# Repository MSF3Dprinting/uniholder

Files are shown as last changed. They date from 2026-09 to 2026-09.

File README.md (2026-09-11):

# UniHolder v1.0

Parametric OpenSCAD holder for items of any size, mountable on walls, vertical or horizontal poles and TS35 DIN rails. Every part prints exactly as generated, standing, with no supports and no overhang beyond `max_overhang`; nothing protrudes into the item space. Made for MSF 3D Printing for All. Design plan: `docs/uniholder_design_plan.md` · test report: `docs/test_report.md`.

## Files

| Path | Content |
|---|---|
| `uniholder.scad` | Main file with all Customizer parameters (needs the `lib/` folder next to it) |
| `uniholder_customizer.scad` | The same model as one self-contained file, for online Customizers running OpenSCAD 2021.01 or newer; tested to give identical geometry |
| `lib/` | `uh_core` maths and screw table · `uh_shapes` printable primitives · `uh_body` shell, walls, hexagons, front opening · `uh_din` DIN rail clip · `uh_mount` back holes, wings, pole mounts |
| `tests/` | `test_shapes.scad` calibration sheet · `test_checker_fail.scad` deliberately unprintable part · variant lists `st2`–`st5` · `examples.json` |
| `tools/` | `run_all_tests.py` complete test suite · `check_overhang.py` STL printability check · `render_matrix.py` batch render · `build_single_file.py` rebuilds the Customizer file |
| `docs/` | Design plan, test report, preview images |

## Quick start

Open `uniholder.scad` or `uniholder_customizer.scad`, show the Customizer (Window → Customizer), set the parameters, render with F6 and export the STL. The console lists `UH INFO` lines (finished size, screws to use) and `UH WARNING` lines when a setting had to be adjusted to fit.

| Tab | Sets |
|---|---|
| Print | `part`: holder · din_clip · holder_and_clip (both on one bed) · din_preview (clip shown mounted, viewing only); overhang limit; quality |
| Size | Item size (inner) or holder size (outer), clearance |
| Walls and edges | Wall, back and floor thickness, corner radii, chamfers, floor cove |
| Wall styles · Hex pattern | Each wall and the floor solid or hexagon-perforated; hexagon size, strut, margins |
| Front opening | Open front with retaining lip and side edges, or a vertical slot |
| Back holes | Ø3–10 mm, plain / countersink / counterbore / keyhole, columns × rows, spacing |
| Wings | Left / right / both, length, thickness, height, on the bed or raised, holes, gusset |
| Pole mount | Vertical or horizontal pole, diameter, V angle, zip ties (count, size, clearance) |
| DIN rail clip | Clip bolt holes in the back wall, bolt size M3–M6, rail height, clip width |

## Printing

- Print exactly as generated and do not rotate the part: the orientation is part of the design. No supports.
- PETG (a light colour for clinical areas), 0.2 mm layers, 4 perimeters, 20–40 % infill (upper end for wings, pole blocks and the clip).
- `max_overhang` = 60 by default; use 45 on printers with weak part cooling — all geometry adapts.
- DIN clip: prints standing on its profile. Enable elephant-foot compensation (about 0.2 mm) so the spring gaps stay open at the first layer.

## Mounting

- **Back holes and wings:** screws matching the hole diameter (default 4.5 mm: M4 or 4 mm wood screws). Countersunk, counterbored and keyhole heads sit flush inside the back wall, which thickens automatically; plain holes leave the head on the inner face.
- **Poles:** standard 5 × 2 mm zip ties (tunnels are 5.5 × 2.5 mm with the default 0.5 mm clearance).
- **DIN rail:** the clip is a separate part. Set `din_holes = true` and choose `din_bolt` (M3–M6); export the holder with `part = holder` and the clip with `part = din_clip`, or both with `part = holder_and_clip`. `part = din_preview` shows the clip mounted on a rail for checking only. The console names the screws, e.g. *2 × M4 × 10 countersunk screws and 2 × M4 nuts*. Put the nuts into the clip's pockets and screw the holder to the clip from inside. Hook the clip over the top of the rail and press the bottom until the latch snaps. To remove, lever the release tab below the spring down with a flat screwdriver and tilt the holder off.

| din_bolt | Hole | Nut | Clip width (auto) | Clip plate | Countersunk screw with default walls |
|---|---|---|---|---|---|
| M3 | 3.4 mm | 5.5 mm AF | 36 mm | 5.0 mm | M3 × 8 |
| M4 | 4.5 mm | 7 mm AF | 36 mm | 5.0 mm | M4 × 10 |
| M5 | 5.5 mm | 8 mm AF | 36 mm | 6.3 mm | M5 × 12 |
| M6 | 6.6 mm | 10 mm AF | 39 mm | 6.8 mm | M6 × 12 |

## Examples

| Example | Parameters (everything else default) |
|---|---|
| Wall cup | defaults: inner 60 × 40 × 80 mm, open front with 20 mm lip, hexagon sides, 2 countersunk back holes |
| Hand-rub bottle on an IV pole | `size_x = 75`, `size_y = 75`, `size_z = 110`, `front_lip_h = 30`, `pole_mount = "vertical"`, `pole_d = 25` |
| DIN rail parts bin | `size_x = 80`, `size_y = 50`, `size_z = 70`, `front_lip_h = 20`, `din_holes = true`; then `part = "din_clip"` |

## Testing

```
python3 tools/run_all_tests.py            # all stages, about 7 minutes; writes docs/test_report.md
python3 tools/run_all_tests.py multi      # one stage: primitives | multi | single | compare | probes | report
```

The suite renders every variant from both `uniholder.scad` and the Customizer file at 60° and 45°, checks each STL for printability, compares the two versions STL by STL, confirms that nothing enters the item space, and fits the DIN clip on a TS35 rail model for every bolt size. Latest result (OpenSCAD 2021.01): primitives pass, 72 of 72 variants pass in each version, 72 of 72 STLs identical, 21 of 21 probes pass — details in `docs/test_report.md`.

For a single model: `python3 tools/check_overhang.py part.stl --max-overhang 60`. After editing `lib/`, rebuild the Customizer file with `python3 tools/build_single_file.py` and rerun the tests.

## Limits

- The DIN clip spring is sized for PETG and standard 1.0 mm TS35 rails (lips up to 1.5 mm); test the snap and release on your own rails before series printing.
- Hexagon hole edges are sharp; cut-out edges are chamfered rather than filleted.
- Features deferred to a later version are listed in the design plan backlog (§8).

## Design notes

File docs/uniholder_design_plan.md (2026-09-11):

# UniHolder — Parametric Universal Holder for OpenSCAD

**Design plan v2.1 (lean) · September 2026** · status: all sub-tasks complete (UniHolder v1.0) — v2.1 adds rule M1 (flush screw heads) after the ST-3 review

v2.0 cuts the v1.1 scope to the core requirements and sizes every remaining sub-task to fit one working session. Nothing is lost: cut features are listed in the backlog (§8).

## 1. Goal

One OpenSCAD file that generates open-top holders for arbitrary items, mountable on walls, vertical or horizontal poles, and DIN rails. Parts print standing, exactly as generated, without supports, and no downward-facing surface exceeds `max_overhang` (60° from vertical by default).

## 2. Scope

| Area | Included |
|---|---|
| Body | Inner or outer size; filleted vertical edges (front and back radius); chamfered top and bed edges; floor cove |
| Walls | Back, left, right, front and floor each solid or hexagon-perforated |
| Front | Solid, hex, **open** (cut down to a retaining lip, side edges kept) or **slot** |
| Wall mounting | Back holes Ø3–10 mm: plain, countersink, counterbore or keyhole, in columns × rows; heads seat flush and the back wall thickens automatically. Wings none / left / right / both: length, height, thickness, holes Ø3–10 mm (count; plain, countersink or slot), gusset |
| Pole mounting | Vertical pole: V-cradle with horizontal zip-tie tunnels. Horizontal pole: V-cradle with vertical zip-tie tunnels |
| DIN rail | Separate TS35 clip with a spring latch, printed on its side, bolted with 2 × M3–M6 bolts through the holder's DIN hole pattern |
| Delivery | Single-file Customizer version; README with print settings and three example configurations |

## 3. Printability rules (unchanged from v1.1)

β = 90° − max_overhang (roof angle above horizontal).

| Rule | Statement |
|---|---|
| P1 | Print as used: Z up, floor on the bed |
| P2 | Downward-facing surfaces ≤ max_overhang from vertical |
| P3 | No floating lowest points: nothing on the holder points downward (hooks and DIN jaws are separate parts) |
| P4 | Horizontal holes are teardrops |
| P5 | Horizontal channels have peaked roofs |
| P6 | Overhanging features get support slopes rising at β |
| P7 | Pointy-top hexagons, whole cells only |
| P8 | Walls and struts ≥ 1.2 mm |
| P9 | Bed edges chamfered 45°, steeper when max_overhang < 45° |
| E1 | Vertical edges filleted |
| E2 | Top edges chamfered |
| E3 | Raised bottom edges sloped at β |
| E4 | Round a corner only where the outline turns upward from a slope |
| M1 | Nothing enters the item space: screw heads seat flush inside the back wall, which thickens as needed (inner mode keeps the item size) |
| — | No text or embossing (cleanability) |

## 4. Conventions

y = 0 is the mounting plane (outer back face); the body extends to −Y and mounts sit at +Y. x = 0 is the centreline; z = 0 is the bed. `0` means auto. `uniholder.scad` holds the parameters and the assembly and includes `lib/uh_core.scad` → `uh_shapes.scad` → `uh_body.scad` → `uh_mount.scad` → `uh_din.scad`. Mount features publish keepout rectangles, so hexagons never cut into mounting zones.

## 5. Customizer parameters (added with their sub-task)

| Tab | Parameters (default) | ST |
|---|---|---|
| Print | max_overhang (60), quality (normal) | 2 |
| Size | size_mode (inner), size_x / size_y / size_z (60 / 40 / 80), item_clr (1) | 2 |
| Walls and edges | wall_t (2.4), back_t (3.2), floor_t (2), corner_r (6), back_corner_r (1.5), chamfer_top (1), chamfer_bottom (0.6), floor_cove (2) | 2 |
| Wall styles | back / left / right / floor_style (solid / hex / hex / solid), front_style (open) | 2 |
| Hex pattern | hex_size (8), hex_strut (2), hex_margin (3), hex_top_band (6), hex_bottom_band (4) | 2 |
| Front opening | front_lip_h (20), front_side_lip_w (8), front_open_r (5), front_slot_w (12), front_slot_z (15) | 2 |
| Back holes | back_holes (true), back_hole_d (4.5), back_hole_style (countersink), back_hole_head_d (0 = 2·d), back_hole_cols (1), back_hole_rows (2), back_hole_pitch_x / z (0 = auto) | 3 |
| Wings | wings (none), wing_len (20), wing_t (4), wing_h (0 = body), wing_align (bottom / top), wing_hole_d (4.5), wing_hole_style (countersink), wing_hole_count (2), wing_gusset (true) | 3 |
| Pole mount | pole_mount (none / vertical / horizontal), pole_d (25), pole_v_angle (90), tie_count (2), tie_w (5), tie_t (2) | 4 |
| DIN clip | part (holder / din_clip / holder_and_clip / din_preview), din_holes (false), din_bolt (M4; M3–M6), din_rail_z (0 = auto), din_clip_w (0 = auto) | 5 |

## 6. Sub-tasks

| ST | Deliverables | Done when |
|---|---|---|
| ST-0 ✓ | Design plan | — |
| ST-1 ✓ | `uh_core.scad`, `uh_shapes.scad`, test sheet, `check_overhang.py` | 8 coupons pass at 60°, 45° and 40° |
| ST-2 ✓ | `uniholder.scad` v0.2, `uh_body.scad`, `render_matrix.py` | Body variants (front modes, hex walls and floor, edge cases) render and pass at 60° and 45° |
| ST-3 ✓ | `uh_mount.scad`: back holes, wings, keepouts | Hole styles and wing variants pass at 60° and 45° |
| ST-4 ✓ | `uh_mount.scad`: vertical and horizontal pole saddles | Pole Ø12–60 mm and tie variants pass at 60° and 45° |
| ST-5 ✓ | `uh_din.scad`, `uniholder_customizer.scad`, README | Clip passes in its print orientation; single file renders the same as the multi-file version |

## 7. Working method per sub-task

1. Write the files.
2. Render a small variant matrix at 60° and 45° in one run (`tools/render_matrix.py`), checking every STL.
3. At most three fix rounds; anything larger moves to the next sub-task.
4. One preview image, then a cumulative zip.

## 8. Backlog (v2)

Slide-in removable front panel, arch window, top hanging tabs, strap slots, magnet pockets, tape recess, dividers, retention lip, clinical-mode switch, slide rail, UMS V1 counterpart (needs reference STEP/STL), HomeRacker pins, French cleat, pegboard / SKÅDIS, edge hook, bolted pole clamp, Customizer JSON presets.

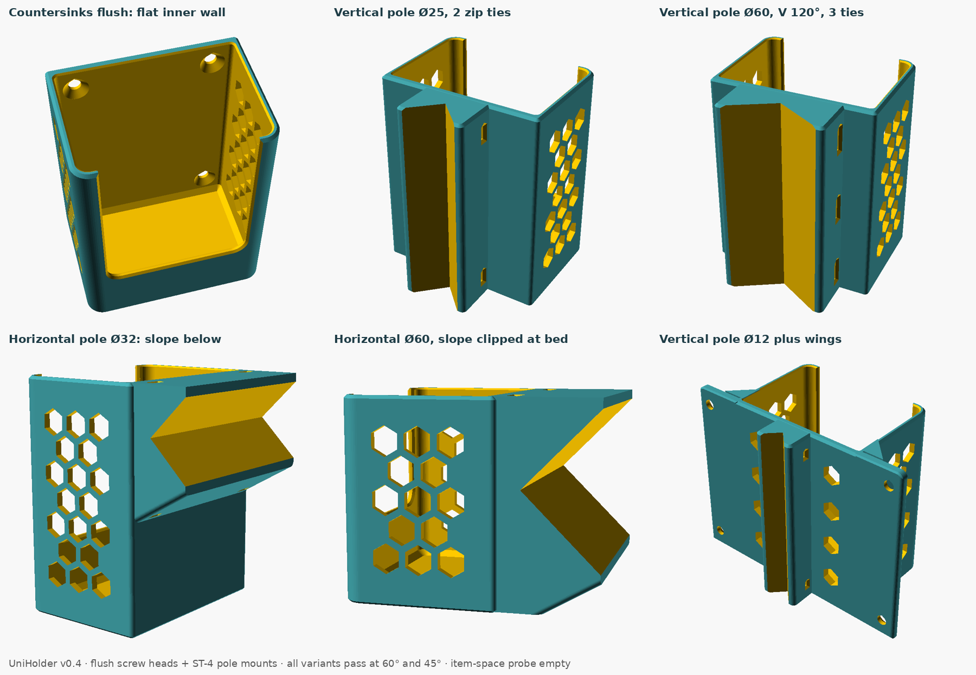
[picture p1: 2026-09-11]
docs/st4_pole_preview.png

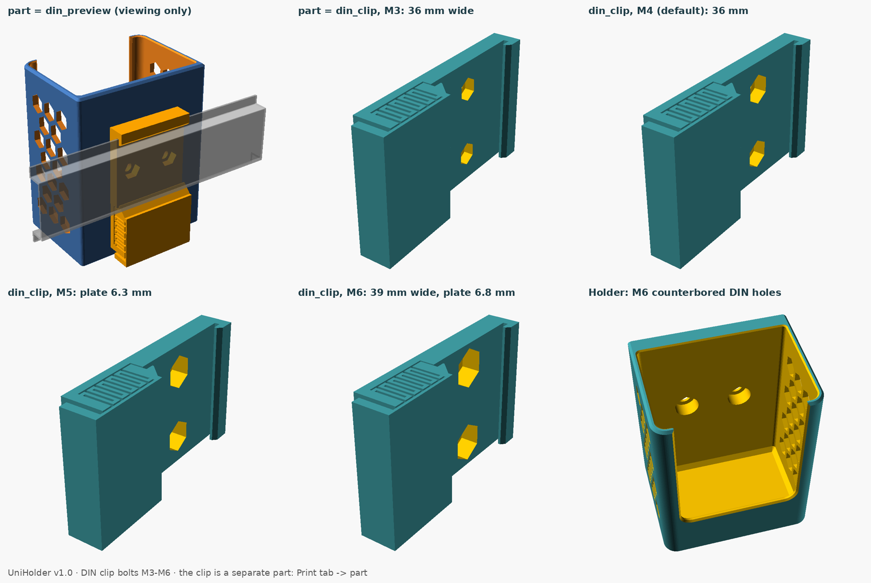
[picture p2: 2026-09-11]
docs/din_bolts_preview.png

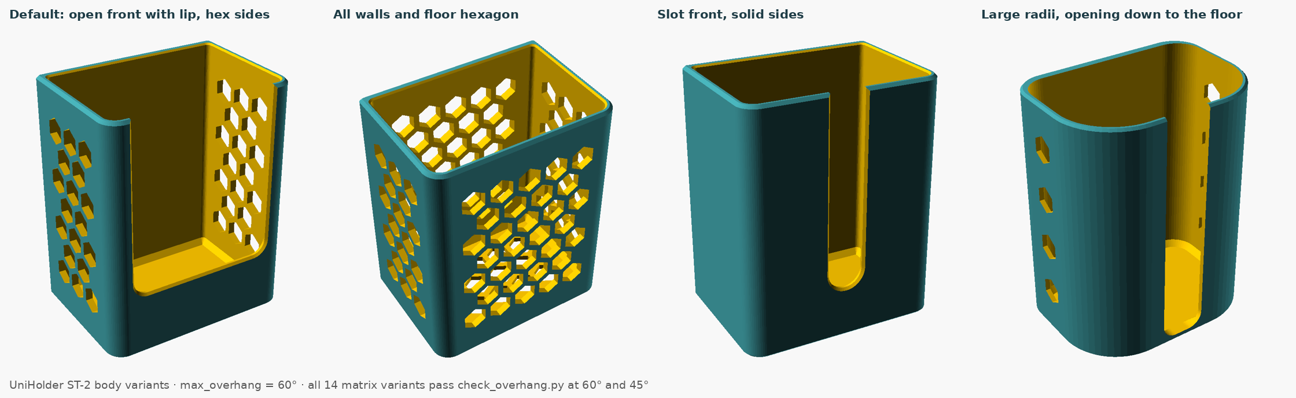
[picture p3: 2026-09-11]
docs/st2_body_preview.png

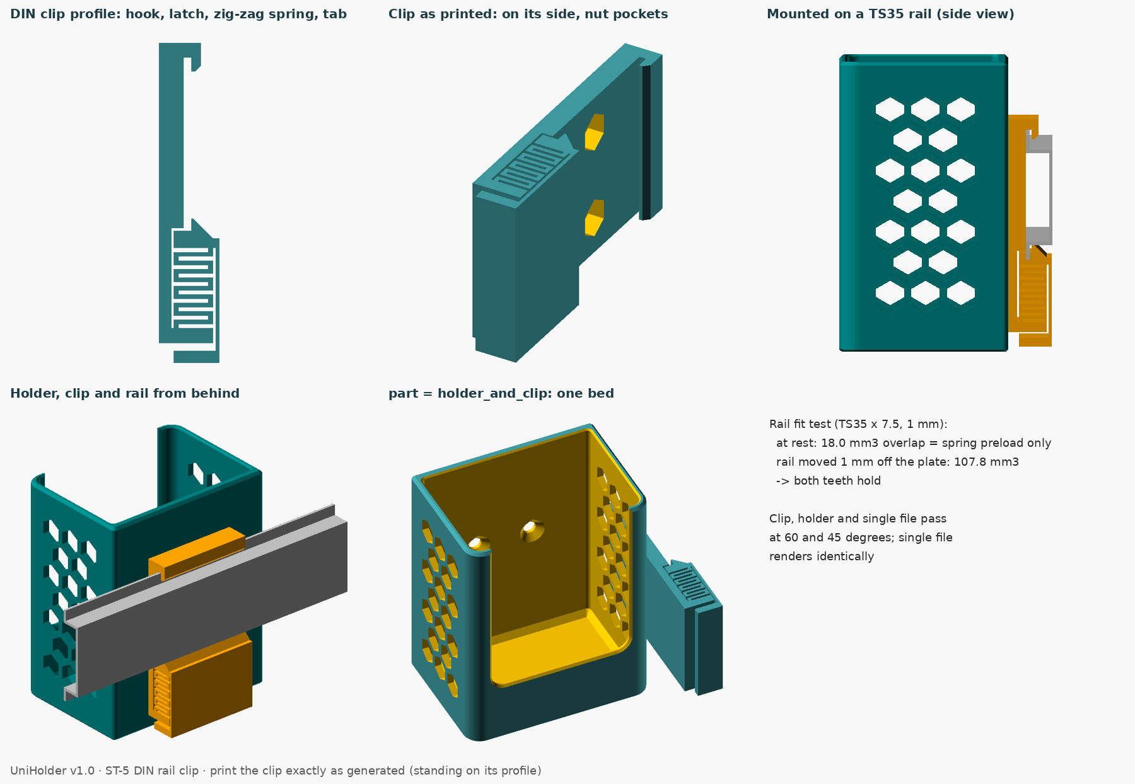
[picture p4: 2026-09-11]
docs/st5_din_preview.png

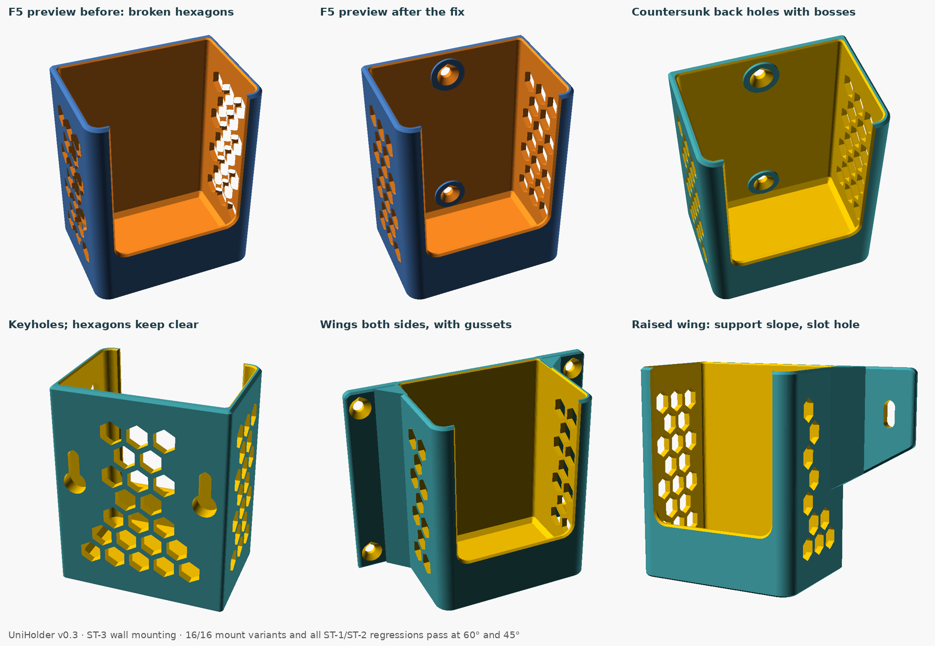
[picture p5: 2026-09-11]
docs/st3_mounting_preview.png

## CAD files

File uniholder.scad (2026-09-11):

// =====================================================================
//  UniHolder — parametric universal holder                        v1.0
//  MSF 3D Printing for All · OpenSCAD 2021.01 or newer · no libraries
//
//  Print exactly as generated: standing on its floor, without supports.
//  No downward-facing surface exceeds max_overhang.
//
//  v1.0 (ST-5): DIN rail clip, single-file Customizer version, zip-tie clearance.
//  v0.4 (ST-4): vertical and horizontal pole mounts with zip-tie tunnels.
//               Screw heads seat flush: the back wall thickens, nothing enters the item space.
//  v0.3 (ST-3): back holes; wings with holes and gussets; cleaner F5 preview.
//  v0.2 (ST-2): body, wall styles, hexagon pattern, front opening.
// =====================================================================

/* [Print] */
// What to generate: holder, DIN rail clip, both on one bed, or din_preview (clip shown mounted, for viewing only)
part = "holder"; // [holder, din_clip, holder_and_clip, din_preview]
// Largest overhang in degrees from vertical (60 default, 45 for weak part cooling)
max_overhang = 60; // [40:5:60]
// Render quality
quality = "normal"; // [draft, normal, fine]

/* [Size] */
// inner = size of the item, outer = size of the finished holder
size_mode = "inner"; // [inner, outer]
// Width (X)
size_x = 60; // [10:0.5:400]
// Depth (Y), front to back
size_y = 40; // [10:0.5:400]
// Height (Z)
size_z = 80; // [10:0.5:400]
// Clearance around the item on each side (inner mode)
item_clr = 1; // [0:0.1:10]

/* [Walls and edges] */
// Side and front wall thickness
wall_t = 2.4; // [1.2:0.1:8]
// Back wall thickness (mounting side)
back_t = 3.2; // [1.6:0.1:10]
// Floor thickness
floor_t = 2; // [0.8:0.1:8]
// Radius of the front vertical edges
corner_r = 6; // [0:0.5:40]
// Radius of the back vertical edges
back_corner_r = 1.5; // [0:0.5:40]
// Chamfer of the top edges
chamfer_top = 1; // [0:0.1:5]
// Chamfer of the edges on the print bed
chamfer_bottom = 0.6; // [0:0.1:3]
// Inner chamfer between floor and walls
floor_cove = 2; // [0:0.5:10]

/* [Wall styles] */
back_style = "solid"; // [solid, hex]
left_style = "hex"; // [solid, hex]
right_style = "hex"; // [solid, hex]
// open = cut down to a retaining lip, slot = narrow vertical slot
front_style = "open"; // [solid, hex, open, slot]
floor_style = "solid"; // [solid, hex]

/* [Hex pattern] */
// Hexagon hole width across flats
hex_size = 8; // [3:0.5:40]
// Material between hexagons
hex_strut = 2; // [1.2:0.1:10]
// Solid border at the wall ends
hex_margin = 3; // [1:0.5:30]
// Solid band below the rim
hex_top_band = 6; // [0:0.5:50]
// Solid band above the floor
hex_bottom_band = 4; // [0:0.5:50]

/* [Front opening] */
// Height of the retaining lip above the inner floor (open)
front_lip_h = 20; // [0:0.5:400]
// Width of the retaining edges left and right (open)
front_side_lip_w = 8; // [1.2:0.5:100]
// Radius of the lower corners of the opening (open)
front_open_r = 5; // [0:0.5:50]
// Slot width (slot)
front_slot_w = 12; // [3:0.5:200]
// Height of the slot bottom above the inner floor (slot)
front_slot_z = 15; // [0:0.5:400]

/* [Back holes] */
// Screw holes in the back wall; screws go in from inside the holder
back_holes = true;
// Hole diameter (screw shank clearance)
back_hole_d = 4.5; // [3:0.5:10]
// countersink, counterbore and keyhole seat the head flush inside the back wall (it thickens as needed); plain leaves the head on the inner face
back_hole_style = "countersink"; // [plain, countersink, counterbore, keyhole]
// Screw head diameter including clearance (0 = 2 × hole diameter)
back_hole_head_d = 0; // [0:0.5:22]
// Number of hole columns
back_hole_cols = 1; // [1:1:6]
// Number of hole rows
back_hole_rows = 2; // [1:1:6]
// Horizontal hole spacing (0 = spread across the back wall)
back_hole_pitch_x = 0; // [0:0.5:300]
// Vertical hole spacing (0 = spread over the height)
back_hole_pitch_z = 0; // [0:0.5:300]

/* [Wings] */
// Mounting wings, flush with the back face
wings = "none"; // [none, left, right, both]
// Wing length beyond the side wall
wing_len = 20; // [8:1:100]
// Wing thickness
wing_t = 4; // [2:0.5:10]
// Wing height at the tip (0 = holder height)
wing_h = 0; // [0:1:400]
// bottom = wing stands on the bed; top = wing hangs from the rim with a support slope below
wing_align = "bottom"; // [bottom, top]
// Hole diameter
wing_hole_d = 4.5; // [3:0.5:10]
// slot = vertical slot for levelling
wing_hole_style = "countersink"; // [plain, countersink, slot]
// Holes per wing
wing_hole_count = 2; // [1:1:4]
// Triangular gusset between wing and side wall
wing_gusset = true;

/* [Pole mount] */
// Mount on a round pole with zip ties (replaces the back holes)
pole_mount = "none"; // [none, vertical, horizontal]
// Pole diameter
pole_d = 25; // [8:0.5:80]
// Included angle of the V-cradle; horizontal poles need at least 2 × (90 − max_overhang)
pole_v_angle = 90; // [60:5:150]
// Number of zip ties
tie_count = 2; // [1:1:6]
// Zip tie width (standard ties: 5 mm)
tie_w = 5; // [2:0.5:14]
// Zip tie thickness (standard ties: 2 mm)
tie_t = 2; // [1:0.1:4]
// Clearance added to the tunnels on width and thickness
tie_clr = 0.5; // [0:0.1:2]

/* [DIN rail clip] */
// Bolt holes for the DIN rail clip in the back wall; the clip is a separate part (Print tab: part)
din_holes = false;
// Bolts joining holder and clip (hole, head and nut sizes follow)
din_bolt = "M4"; // [M3, M4, M5, M6]
// Height of the rail centreline on the holder (0 = automatic)
din_rail_z = 0; // [0:0.5:400]
// Clip width along the rail (0 = automatic)
din_clip_w = 0; // [0:1:100]

/* [Hidden] */
include <lib/uh_core.scad>
include <lib/uh_shapes.scad>
include <lib/uh_body.scad>
include <lib/uh_din.scad>
include <lib/uh_mount.scad>

$fa = uh_quality(quality)[0];
$fs = uh_quality(quality)[1];

// Test hooks (not shown in the Customizer):
//   cavity_probe      what intrudes into the item space - must be empty
//   din_fit           holder, clip and a TS35 rail in their mounted positions
//   din_interference  clip and rail overlap at rest - only the spring preload
//   din_pullout       overlap with the rail moved 1 mm off the plate - the teeth hold
debug_view = "none";

uh_body_checks();
uh_mount_checks();

if      (debug_view == "cavity_probe")     intersection() { uh_holder(); uh_item_space(); }
else if (debug_view == "din_fit")          { color("teal") uh_holder(); color("orange") uh_din_clip_in_use(); color("silver") uh_din_rail(); }
else if (debug_view == "din_interference") intersection() { uh_din_clip_in_use(); uh_din_rail(); }
else if (debug_view == "din_pullout")      intersection() { uh_din_clip_in_use(); uh_din_rail(1); }
else if (part == "din_clip")               uh_din_clip();
else if (part == "holder_and_clip")        { uh_holder(); uh_din_clip_beside(); }
else if (part == "din_preview")            { uh_holder(); color("orange") uh_din_clip_in_use(); %uh_din_rail(); }
else                                       uh_holder();

// Assembly order: shell − cavity, add mount features, then cut
// perforations, the front opening and the mount holes last.
module uh_holder() {
    difference() {
        union() {
            difference() {
                uh_outer_shell();
                uh_cavity();
            }
            uh_mount_external();   // wings and gussets
        }
        uh_perforations();         // hexagons, clear of mount keepouts
        uh_front_opening();
        uh_mount_cutters();        // back holes and wing holes
    }
}

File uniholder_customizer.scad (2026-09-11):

// UniHolder - single-file Customizer version, generated by tools/build_single_file.py.
// Same model as uniholder.scad + lib/ in one file (tested identical geometry).
// =====================================================================
//  UniHolder — parametric universal holder                        v1.0
//  MSF 3D Printing for All · OpenSCAD 2021.01 or newer · no libraries
//
//  Print exactly as generated: standing on its floor, without supports.
//  No downward-facing surface exceeds max_overhang.
//
//  v1.0 (ST-5): DIN rail clip, single-file Customizer version, zip-tie clearance.
//  v0.4 (ST-4): vertical and horizontal pole mounts with zip-tie tunnels.
//               Screw heads seat flush: the back wall thickens, nothing enters the item space.
//  v0.3 (ST-3): back holes; wings with holes and gussets; cleaner F5 preview.
//  v0.2 (ST-2): body, wall styles, hexagon pattern, front opening.
// =====================================================================

/* [Print] */
// What to generate: holder, DIN rail clip, both on one bed, or din_preview (clip shown mounted, for viewing only)
part = "holder"; // [holder, din_clip, holder_and_clip, din_preview]
// Largest overhang in degrees from vertical (60 default, 45 for weak part cooling)
max_overhang = 60; // [40:5:60]
// Render quality
quality = "normal"; // [draft, normal, fine]

/* [Size] */
// inner = size of the item, outer = size of the finished holder
size_mode = "inner"; // [inner, outer]
// Width (X)
size_x = 60; // [10:0.5:400]
// Depth (Y), front to back
size_y = 40; // [10:0.5:400]
// Height (Z)
size_z = 80; // [10:0.5:400]
// Clearance around the item on each side (inner mode)
item_clr = 1; // [0:0.1:10]

/* [Walls and edges] */
// Side and front wall thickness
wall_t = 2.4; // [1.2:0.1:8]
// Back wall thickness (mounting side)
back_t = 3.2; // [1.6:0.1:10]
// Floor thickness
floor_t = 2; // [0.8:0.1:8]
// Radius of the front vertical edges
corner_r = 6; // [0:0.5:40]
// Radius of the back vertical edges
back_corner_r = 1.5; // [0:0.5:40]
// Chamfer of the top edges
chamfer_top = 1; // [0:0.1:5]
// Chamfer of the edges on the print bed
chamfer_bottom = 0.6; // [0:0.1:3]
// Inner chamfer between floor and walls
floor_cove = 2; // [0:0.5:10]

/* [Wall styles] */
back_style = "solid"; // [solid, hex]
left_style = "hex"; // [solid, hex]
right_style = "hex"; // [solid, hex]
// open = cut down to a retaining lip, slot = narrow vertical slot
front_style = "open"; // [solid, hex, open, slot]
floor_style = "solid"; // [solid, hex]

/* [Hex pattern] */
// Hexagon hole width across flats
hex_size = 8; // [3:0.5:40]
// Material between hexagons
hex_strut = 2; // [1.2:0.1:10]
// Solid border at the wall ends
hex_margin = 3; // [1:0.5:30]
// Solid band below the rim
hex_top_band = 6; // [0:0.5:50]
// Solid band above the floor
hex_bottom_band = 4; // [0:0.5:50]

/* [Front opening] */
// Height of the retaining lip above the inner floor (open)
front_lip_h = 20; // [0:0.5:400]
// Width of the retaining edges left and right (open)
front_side_lip_w = 8; // [1.2:0.5:100]
// Radius of the lower corners of the opening (open)
front_open_r = 5; // [0:0.5:50]
// Slot width (slot)
front_slot_w = 12; // [3:0.5:200]
// Height of the slot bottom above the inner floor (slot)
front_slot_z = 15; // [0:0.5:400]

/* [Back holes] */
// Screw holes in the back wall; screws go in from inside the holder
back_holes = true;
// Hole diameter (screw shank clearance)
back_hole_d = 4.5; // [3:0.5:10]
// countersink, counterbore and keyhole seat the head flush inside the back wall (it thickens as needed); plain leaves the head on the inner face
back_hole_style = "countersink"; // [plain, countersink, counterbore, keyhole]
// Screw head diameter including clearance (0 = 2 × hole diameter)
back_hole_head_d = 0; // [0:0.5:22]
// Number of hole columns
back_hole_cols = 1; // [1:1:6]
// Number of hole rows
back_hole_rows = 2; // [1:1:6]
// Horizontal hole spacing (0 = spread across the back wall)
back_hole_pitch_x = 0; // [0:0.5:300]
// Vertical hole spacing (0 = spread over the height)
back_hole_pitch_z = 0; // [0:0.5:300]

/* [Wings] */
// Mounting wings, flush with the back face
wings = "none"; // [none, left, right, both]
// Wing length beyond the side wall
wing_len = 20; // [8:1:100]
// Wing thickness
wing_t = 4; // [2:0.5:10]
// Wing height at the tip (0 = holder height)
wing_h = 0; // [0:1:400]
// bottom = wing stands on the bed; top = wing hangs from the rim with a support slope below
wing_align = "bottom"; // [bottom, top]
// Hole diameter
wing_hole_d = 4.5; // [3:0.5:10]
// slot = vertical slot for levelling
wing_hole_style = "countersink"; // [plain, countersink, slot]
// Holes per wing
wing_hole_count = 2; // [1:1:4]
// Triangular gusset between wing and side wall
wing_gusset = true;

/* [Pole mount] */
// Mount on a round pole with zip ties (replaces the back holes)
pole_mount = "none"; // [none, vertical, horizontal]
// Pole diameter
pole_d = 25; // [8:0.5:80]
// Included angle of the V-cradle; horizontal poles need at least 2 × (90 − max_overhang)
pole_v_angle = 90; // [60:5:150]
// Number of zip ties
tie_count = 2; // [1:1:6]
// Zip tie width (standard ties: 5 mm)
tie_w = 5; // [2:0.5:14]
// Zip tie thickness (standard ties: 2 mm)
tie_t = 2; // [1:0.1:4]
// Clearance added to the tunnels on width and thickness
tie_clr = 0.5; // [0:0.1:2]

/* [DIN rail clip] */
// Bolt holes for the DIN rail clip in the back wall; the clip is a separate part (Print tab: part)
din_holes = false;
// Bolts joining holder and clip (hole, head and nut sizes follow)
din_bolt = "M4"; // [M3, M4, M5, M6]
// Height of the rail centreline on the holder (0 = automatic)
din_rail_z = 0; // [0:0.5:400]
// Clip width along the rail (0 = automatic)
din_clip_w = 0; // [0:1:100]

/* [Hidden] */
// ==== begin lib/uh_core.scad ====
// =====================================================================
//  UniHolder — lib/uh_core.scad                                   ST-1
//  Constants, overhang math, hexagon math and console helpers.
//
//  Dependency-free; OpenSCAD 2021.01 language subset.
//  Libraries never include each other. Include them in this order:
//      include <lib/uh_core.scad>
//      include <lib/uh_shapes.scad>
//
//  Conventions (design plan §3–§4)
//    * Overhang angles are measured FROM VERTICAL: 0° = wall, 90° = ceiling.
//    * beta = 90° − max_overhang is the minimum rise of any downward-facing
//      surface above horizontal (the "roof angle").
//    * +Z is up in use and on the print bed. Units: mm and degrees.
//
//  Public API
//    Generic     uh_clamp  uh_auto  uh_approx  uh_quality  uh_fragments  uh_poly_r
//    Overhang    uh_beta  uh_rise  uh_run  uh_teardrop_apex  uh_roof_h
//                uh_overhang_of_nz  uh_flare_len  uh_chamfer_h  uh_chamfer_depth
//                uh_countersink_depth  uh_metric
//    Hexagon     uh_hex_flank  uh_hex_peak  uh_hex_dims  uh_hex_pitch
//    Console     uh_warn  uh_info  uh_warn_f  uh_clamp_warn
//    Transforms  uh_mirror_copy
//    Tests       uh_core_selftest
// =====================================================================

UH_CORE_VERSION = "0.1.0";

UH_EPS  = 0.01;    // overlap on coincident union / difference faces
UH_TINY = 0.001;   // thickness of construction slices
UH_BIG  = 4000;    // size of clipping volumes

UH_OVERHANG_MIN = 40;   // supported range of max_overhang
UH_OVERHANG_MAX = 60;

// ---------------------------------------------------------------------
//  Generic helpers
// ---------------------------------------------------------------------

function uh_clamp(x, lo, hi) = min(max(x, lo), hi);

// "0 means auto" convention for optional dimensions
function uh_auto(value, auto_value) = value == 0 ? auto_value : value;

function uh_approx(a, b, tol = 1e-6) = abs(a - b) <= tol;

// Quality preset -> [$fa, $fs]
function uh_quality(q) =
      q == "draft" ? [12, 1.0]
    : q == "fine"  ? [3, 0.2]
    :                [6, 0.4];

// Fragments OpenSCAD uses for a circle of radius r (same rule as the renderer)
function uh_fragments(r) =
      r < 1e-5 ? 3
    : $fn > 0  ? max($fn, 3)
    :            ceil(max(min(360 / $fa, r * 2 * PI / $fs), 5));

// Vertex radius of an n-gon whose flats sit at radius r.
// Used for clearance holes, so a printed hole is never undersized.
function uh_poly_r(r, n) = r / cos(180 / n);

// ---------------------------------------------------------------------
//  Overhang math (rules P2, P4, P5, P6)
// ---------------------------------------------------------------------

// Roof angle: minimum rise of a downward-facing surface above horizontal
function uh_beta(max_overhang) = 90 - max_overhang;

// Height a support slope gains over a horizontal run
function uh_rise(run, max_overhang) = run * tan(uh_beta(max_overhang));

// Horizontal run a support slope needs to gain a given height
function uh_run(rise, max_overhang) = rise / tan(uh_beta(max_overhang));
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

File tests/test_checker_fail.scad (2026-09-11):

// =====================================================================
//  UniHolder — tests/test_checker_fail.scad                       ST-1
//  Deliberately UNPRINTABLE coupon. tools/check_overhang.py must FAIL on it:
//    A  rectangular hole with a flat ceiling          -> P2 (90° overhang)
//    B  arm with a 45° underside (fine) carrying a
//       downward-pointing cone (sides fine, apex floats) -> P3 only
// =====================================================================
$fa = 6; $fs = 0.4;

difference() {
    translate([-20, -3, 0]) cube([40, 6, 30]);
    translate([-10, 0, 12]) cube([10, 8, 6], center = true);        // A
}

// B: printable arm growing out of the +Y face with a 45° support slope
hull() {
    translate([6, 2.99, 20]) cube([8, 10, 4]);
    translate([6, 2.99, 10]) cube([8, 0.01, 14]);
}
// cone hanging below the arm tip: faces are ~11° from vertical, but the apex floats
translate([10, 11, 8]) cylinder(h = 12.5, r1 = 0, r2 = 2.5);

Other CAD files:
tests/test_shapes.scad

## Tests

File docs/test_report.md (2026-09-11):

# UniHolder v1.0 — test report

Generated 2026-09-11 with OpenSCAD version 2021.01 by `tools/run_all_tests.py`. Every STL is checked by `tools/check_overhang.py` (downward facets steeper than the limit, floating lowest points, open or non-manifold edges).

| Stage | Result | Details |
|---|---|---|
| Primitives | PASS | calibration sheet at 60°, 45°, 40°; negative test rejected |
| Variants from `uniholder.scad` | PASS | 72 of 72 pass |
| Variants from `uniholder_customizer.scad` | PASS | 72 of 72 pass |
| Customizer file identical to multi-file | PASS | 72 of 72 STLs identical (facets, volume, bounding box) |
| Probes | PASS | 21 of 21 pass |

## Primitives

| Test | Expected | Result | Worst overhang | Note |
|---|---|---|---|---|
| tests/test_shapes.scad at 60 deg | PASS | PASS | 60.0° | core self-test passed |
| tests/test_shapes.scad at 45 deg | PASS | PASS | 45.02° | core self-test passed |
| tests/test_shapes.scad at 40 deg | PASS | PASS | 40.02° | core self-test passed |
| tests/test_checker_fail.scad (must be rejected) | FAIL | FAIL | 90.0° | 2 steep facets, 1 floating points |

## Variants

Worst overhang equal to the limit means surfaces sit exactly at the limit, never beyond it.

| Variant | Limit | Multi-file | Customizer file | Identical | Worst | Floating | Open / non-manifold | Size [mm] |
|---|---|---|---|---|---|---|---|---|
| st2.default | 60° | PASS | PASS | yes | 60.00° | 0 | 0/0 | 66.8 x 47.9 x 82.0 |
| st2.default | 45° | PASS | PASS | yes | 45.00° | 0 | 0/0 | 66.8 x 47.9 x 82.0 |
| st2.allhex | 60° | PASS | PASS | yes | 60.00° | 0 | 0/0 | 66.8 x 47.9 x 82.0 |
| st2.allhex | 45° | PASS | PASS | yes | 45.00° | 0 | 0/0 | 66.8 x 47.9 x 82.0 |
| st2.slot | 60° | PASS | PASS | yes | 60.00° | 0 | 0/0 | 66.8 x 47.9 x 82.0 |
| st2.slot | 45° | PASS | PASS | yes | 45.00° | 0 | 0/0 | 66.8 x 47.9 x 82.0 |
| st2.outer_sharp | 60° | PASS | PASS | yes | 60.00° | 0 | 0/0 | 50.0 x 30.0 x 40.0 |
| st2.outer_sharp | 45° | PASS | PASS | yes | 45.00° | 0 | 0/0 | 50.0 x 30.0 x 40.0 |
| st2.bigr_lip0 | 60° | PASS | PASS | yes | 60.00° | 0 | 0/0 | 65.2 x 47.0 x 82.0 |
| st2.bigr_lip0 | 45° | PASS | PASS | yes | 45.00° | 0 | 0/0 | 65.2 x 47.0 x 82.0 |
| st2.tiny | 60° | PASS | PASS | yes | 60.00° | 0 | 0/0 | 26.8 x 22.9 x 27.0 |
| st2.tiny | 45° | PASS | PASS | yes | 45.00° | 0 | 0/0 | 26.8 x 22.9 x 27.0 |
| st2.wide_low | 60° | PASS | PASS | yes | 60.00° | 0 | 0/0 | 186.8 x 67.8 x 37.0 |
| st2.wide_low | 45° | PASS | PASS | yes | 45.00° | 0 | 0/0 | 186.8 x 67.8 x 37.0 |
| st3.holes_default | 60° | PASS | PASS | yes | 60.00° | 0 | 0/0 | 66.8 x 47.9 x 82.0 |
| st3.holes_default | 45° | PASS | PASS | yes | 45.00° | 0 | 0/0 | 66.8 x 47.9 x 82.0 |
| st3.holes_plain_hex | 60° | PASS | PASS | yes | 60.00° | 0 | 0/0 | 66.8 x 47.6 x 82.0 |
| st3.holes_plain_hex | 45° | PASS | PASS | yes | 45.00° | 0 | 0/0 | 66.8 x 47.6 x 82.0 |
| st3.holes_cb_pitch | 60° | PASS | PASS | yes | 60.00° | 0 | 0/0 | 66.8 x 48.6 x 82.0 |
| st3.holes_cb_pitch | 45° | PASS | PASS | yes | 45.00° | 0 | 0/0 | 66.8 x 48.6 x 82.0 |
| st3.keyhole_hex | 60° | PASS | PASS | yes | 60.00° | 0 | 0/0 | 66.8 x 51.1 x 82.0 |
| st3.keyhole_hex | 45° | PASS | PASS | yes | 45.00° | 0 | 0/0 | 66.8 x 51.1 x 82.0 |
| st3.wings_both | 60° | PASS | PASS | yes | 60.00° | 0 | 0/0 | 106.8 x 47.6 x 82.0 |
| st3.wings_both | 45° | PASS | PASS | yes | 45.08° | 0 | 0/0 | 106.8 x 47.6 x 82.0 |
| st3.wing_raised_slot | 60° | PASS | PASS | yes | 60.00° | 0 | 0/0 | 96.8 x 47.9 x 82.0 |
| st3.wing_raised_slot | 45° | PASS | PASS | yes | 45.00° | 0 | 0/0 | 96.8 x 47.9 x 82.0 |
| st3.wing_d10_thick | 60° | PASS | PASS | yes | 60.00° | 0 | 0/0 | 106.8 x 47.9 x 82.0 |
| st3.wing_d10_thick | 45° | PASS | PASS | yes | 45.00° | 0 | 0/0 | 106.8 x 47.9 x 82.0 |
| st3.wing_short_many | 60° | PASS | PASS | yes | 60.00° | 0 | 0/0 | 90.8 x 47.9 x 82.0 |
| st3.wing_short_many | 45° | PASS | PASS | yes | 45.00° | 0 | 0/0 | 90.8 x 47.9 x 82.0 |
| st4.vpole_default | 60° | PASS | PASS | yes | 60.00° | 0 | 0/0 | 66.8 x 65.3 x 82.0 |
| st4.vpole_default | 45° | PASS | PASS | yes | 45.01° | 0 | 0/0 | 66.8 x 65.3 x 82.0 |
| st4.vpole_d60_v120 | 60° | PASS | PASS | yes | 60.00° | 0 | 0/0 | 66.8 x 65.7 x 82.0 |
| st4.vpole_d60_v120 | 45° | PASS | PASS | yes | 45.00° | 0 | 0/0 | 66.8 x 65.7 x 82.0 |
| st4.vpole_d12_wings | 60° | PASS | PASS | yes | 60.00° | 0 | 0/0 | 106.8 x 59.9 x 82.0 |
| st4.vpole_d12_wings | 45° | PASS | PASS | yes | 46.36° | 0 | 0/0 | 106.8 x 59.9 x 82.0 |
| st4.hpole_d32 | 60° | PASS | PASS | yes | 60.00° | 0 | 0/0 | 66.8 x 67.8 x 82.0 |
| st4.hpole_d32 | 45° | PASS | PASS | yes | 45.00° | 0 | 0/0 | 66.8 x 67.8 x 82.0 |
| st4.hpole_v60_hex | 60° | PASS | PASS | yes | 60.00° | 0 | 0/0 | 66.8 x 75.2 x 82.0 |
| st4.hpole_v60_hex | 45° | PASS | PASS | yes | 45.00° | 0 | 0/0 | 66.8 x 65.3 x 82.0 |
| st4.hpole_d60_low | 60° | PASS | PASS | yes | 60.00° | 0 | 0/0 | 66.8 x 78.2 x 62.0 |
| st4.hpole_d60_low | 45° | PASS | PASS | yes | 45.00° | 0 | 0/0 | 66.8 x 78.2 x 62.0 |
| st5.din_clip_m3 | 60° | PASS | PASS | yes | 60.00° | 0 | 0/0 | 12.2 x 64.4 x 36.0 |
| st5.din_clip_m3 | 45° | PASS | PASS | yes | 45.00° | 0 | 0/0 | 12.2 x 64.4 x 36.0 |
| st5.din_clip_m4 | 60° | PASS | PASS | yes | 60.00° | 0 | 0/0 | 12.2 x 64.4 x 36.0 |
| st5.din_clip_m4 | 45° | PASS | PASS | yes | 45.00° | 0 | 0/0 | 12.2 x 64.4 x 36.0 |
| st5.din_clip_m5 | 60° | PASS | PASS | yes | 60.00° | 0 | 0/0 | 13.5 x 64.4 x 36.0 |
| st5.din_clip_m5 | 45° | PASS | PASS | yes | 45.00° | 0 | 0/0 | 13.5 x 64.4 x 36.0 |
| st5.din_clip_m6 | 60° | PASS | PASS | yes | 60.00° | 0 | 0/0 | 14.0 x 64.4 x 39.0 |
| st5.din_clip_m6 | 45° | PASS | PASS | yes | 45.00° | 0 | 0/0 | 14.0 x 64.4 x 43.0 |
| st5.din_clip_w50 | 60° | PASS | PASS | yes | 60.00° | 0 | 0/0 | 12.2 x 64.4 x 50.0 |
| st5.din_clip_w50 | 45° | PASS | PASS | yes | 45.00° | 0 | 0/0 | 12.2 x 64.4 x 50.0 |
| st5.din_holes_m3 | 60° | PASS | PASS | yes | 60.00° | 0 | 0/0 | 66.8 x 47.6 x 82.0 |
| st5.din_holes_m3 | 45° | PASS | PASS | yes | 45.00° | 0 | 0/0 | 66.8 x 47.6 x 82.0 |
| st5.din_holes_m4 | 60° | PASS | PASS | yes | 60.00° | 0 | 0/0 | 66.8 x 48.1 x 82.0 |
| st5.din_holes_m4 | 45° | PASS | PASS | yes | 45.00° | 0 | 0/0 | 66.8 x 48.1 x 82.0 |
| st5.din_holes_m6_cb_hex | 60° | PASS | PASS | yes | 60.00° | 0 | 0/0 | 66.8 x 52.0 x 82.0 |
| st5.din_holes_m6_cb_hex | 45° | PASS | PASS | yes | 45.00° | 0 | 0/0 | 66.8 x 52.0 x 82.0 |
| st5.din_holes_m5_keyhole | 60° | PASS | PASS | yes | 60.00° | 0 | 0/0 | 66.8 x 48.7 x 82.0 |
| st5.din_holes_m5_keyhole | 45° | PASS | PASS | yes | 45.00° | 0 | 0/0 | 66.8 x 48.7 x 82.0 |
| st5.holder_and_clip_m5 | 60° | PASS | PASS | yes | 60.00° | 0 | 0/0 | 110.3 x 64.4 x 82.0 |
| st5.holder_and_clip_m5 | 45° | PASS | PASS | yes | 45.07° | 0 | 0/0 | 110.3 x 64.4 x 82.0 |
| st5.vpole_tie_clr | 60° | PASS | PASS | yes | 60.00° | 0 | 0/0 | 66.8 x 65.3 x 82.0 |
| st5.vpole_tie_clr | 45° | PASS | PASS | yes | 45.01° | 0 | 0/0 | 66.8 x 65.3 x 82.0 |
| examples.ex1_wall_cup | 60° | PASS | PASS | yes | 60.00° | 0 | 0/0 | 66.8 x 47.9 x 82.0 |
| examples.ex1_wall_cup | 45° | PASS | PASS | yes | 45.00° | 0 | 0/0 | 66.8 x 47.9 x 82.0 |
| examples.ex2_iv_pole_bottle | 60° | PASS | PASS | yes | 60.00° | 0 | 0/0 | 81.8 x 100.3 x 112.0 |
| examples.ex2_iv_pole_bottle | 45° | PASS | PASS | yes | 45.01° | 0 | 0/0 | 81.8 x 100.3 x 112.0 |
| examples.ex3_din_parts_bin | 60° | PASS | PASS | yes | 60.00° | 0 | 0/0 | 86.8 x 58.1 x 72.0 |
| examples.ex3_din_parts_bin | 45° | PASS | PASS | yes | 45.00° | 0 | 0/0 | 86.8 x 58.1 x 72.0 |
| examples.ex3_din_clip | 60° | PASS | PASS | yes | 60.00° | 0 | 0/0 | 12.2 x 64.4 x 36.0 |
| examples.ex3_din_clip | 45° | PASS | PASS | yes | 45.00° | 0 | 0/0 | 12.2 x 64.4 x 36.0 |

## Console warnings (intended adjustments)

- back holes reduced to 1 x 1 so the heads do not overlap — st2.tiny
- back wall thickened to 3.45 mm to seat the screw heads - inner depth is reduced — st2.outer_sharp
- back: no room for a whole hexagon, wall stays solid — st5.din_holes_m6_cb_hex
- keyholes cannot hold the DIN clip - countersunk holes are used — st5.din_holes_m5_keyhole
- left: no room for a whole hexagon, wall stays solid — st2.tiny
- pole_v_angle = 60 clamped to 90 — st4.hpole_v60_hex
- right: no room for a whole hexagon, wall stays solid — st2.tiny
- uh_screw_hole: countersink depth 5 leaves less than 1.2 mm of wall — st3.wing_d10_thick
- wing_hole_count reduced to 3 to fit the wing — st3.wing_short_many

## Probes

| Probe | Expected | Measured | Result |
|---|---|---|---|
| item space empty: countersink back holes | empty | empty | PASS |
| item space empty: counterbore back holes | empty | empty | PASS |
| item space empty: keyholes | empty | empty | PASS |
| item space empty: plain holes, hex back | empty | empty | PASS |
| item space empty: wings with 10 mm holes | empty | empty | PASS |
| item space empty: vertical pole | empty | empty | PASS |
| item space empty: horizontal pole | empty | empty | PASS |
| item space empty: DIN M6 counterbore | empty | empty | PASS |
| item space empty: DIN M3 countersink | empty | empty | PASS |
| item space empty: DIN M4 countersink | empty | empty | PASS |
| item space empty: DIN M5 countersink | empty | empty | PASS |
| item space empty: DIN M6 countersink | empty | empty | PASS |
| DIN M3 clip at rest on TS35 | preload | 18.0 mm3 (preload 18.0 mm3) | PASS |
| DIN M4 clip at rest on TS35 | preload | 18.0 mm3 (preload 18.0 mm3) | PASS |
| DIN M5 clip at rest on TS35 | preload | 18.0 mm3 (preload 18.0 mm3) | PASS |
| DIN M6 clip at rest on TS35 | preload | 19.5 mm3 (preload 19.5 mm3) | PASS |
| DIN M3 rail pulled 1 mm off the plate | holds | 107.82 mm3 (at least 3 x preload 18.0 mm3) | PASS |
| DIN M4 rail pulled 1 mm off the plate | holds | 107.82 mm3 (at least 3 x preload 18.0 mm3) | PASS |
| DIN M5 rail pulled 1 mm off the plate | holds | 107.82 mm3 (at least 3 x preload 18.0 mm3) | PASS |
| DIN M6 rail pulled 1 mm off the plate | holds | 116.805 mm3 (at least 3 x preload 19.5 mm3) | PASS |
| part = din_preview renders with warning | renders | 57118.589 mm3 | PASS |

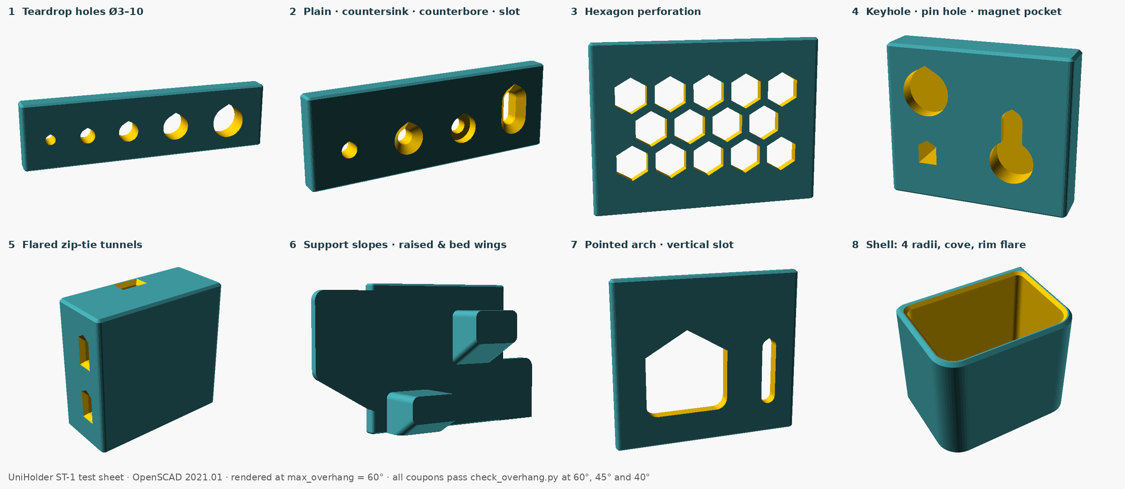
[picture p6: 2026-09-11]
docs/st1_test_sheet_preview.png
